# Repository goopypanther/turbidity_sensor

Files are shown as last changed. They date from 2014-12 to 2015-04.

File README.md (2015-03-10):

Water Turbidity Sensor Project
==============================

Hackerbot labs would like to place a number of water turbidity sensor packages in dive sites around Puget Sound to provide up-to-date visibility and water temperature information.

The sensor string will be suspended between a weight and small buoy which will contain a battery, solar panels and communication antenna. The installations will be close to shore and will probably use local wifi or a LTE cellular data connection.

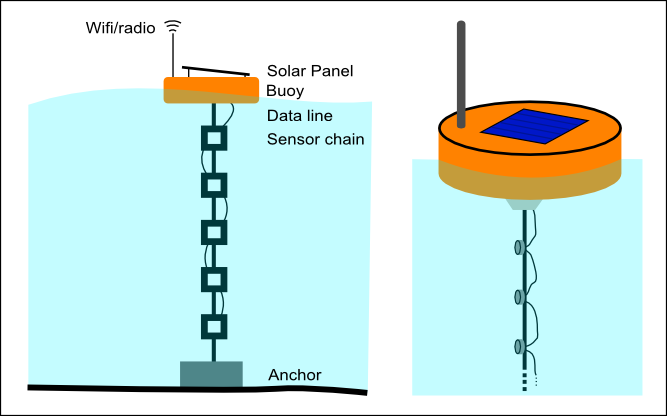
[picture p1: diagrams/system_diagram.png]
image of system diagram


Research
--------

[This folder](https://github.com/JeremyRuhland/turbidity_sensor/tree/master/research) contains information and design specs related to the sensor packages and their installation.

Prototypes
----------

[This folder](https://github.com/JeremyRuhland/turbidity_sensor/tree/master/prototypes) contains schematics and code used for prototype systems intented to guide the design of the sensors and their housings.

Designs
-------

[This folder](https://github.com/JeremyRuhland/turbidity_sensor/tree/master/designs) contains possible designs for the production sensor strings.

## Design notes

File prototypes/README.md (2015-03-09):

Prototypes
==========

Rev0
----

[This prototype](https://github.com/JeremyRuhland/turbidity_sensor/tree/master/prototypes/rev0) is the original design [JeremyRuhland](https://github.com/JeremyRuhland) came up with without doing any research or testing, so it probably won't work. This will probably never see the water but some design aspects may be useful for further equipment.

Rev1
----

[This prototype](https://github.com/JeremyRuhland/turbidity_sensor/tree/master/prototypes/rev1) is designed for testing differences between opacity measurements and rayleigh scattering. It is described further in its own readme file.

Rev2
----

[This prototype](https://github.com/JeremyRuhland/turbidity_sensor/tree/master/prototypes/rev2) is designed for testing the utility of UV light based biofouling mitigation. It is described further in its own readme file.

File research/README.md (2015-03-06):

Research
========

Research materials and notes go here.

Turbidity
---------

Particles both scatter and absorb light, scattered light may be a better indicator of clarity than absorbed light because of translucent particles.

Research suggests infrared light is ideal for its indifference to the color of particular organic particles. 940nm (IR) LEDs and photodiodes are readily available. 850nm (closer to NIR) are also an option.

Biofouling
----------

Research suggests ultraviolet light can reduce the amount of biological growth on sensor surfaces. UVC will kill everything from barnacles to biofilms ([1](https://www.ncbi.nlm.nih.gov/pubmed/20024789), [2](https://www.oceannews.com/feature-story/2014/03/04/february-uv-irradiation-a-new-kind-of-antifoulant)) but LEDs are very expensive (>$100 each). Cheap UVA LEDs may provide some protection ([1](http://onlinelibrary.wiley.com/doi/10.1111/j.1365-2672.2010.04850.x/full)) but other studies seem to indicate that some species respond favorably to it ([1](http://plankt.oxfordjournals.org/content/16/12/1645.short), [2](https://www.ncbi.nlm.nih.gov/pubmed/17039372)), though this might differ between soil/freshwater/marine environments.

Measurement & Conversion
------------------------

Some possible discussed architectures:

 * Direct measurement of photodiodes
 * Transimpedence amplifier -> ADC
 * Closed loop LED intensity/transimpedence -> ADC
  * Automatic gain control

Other ideas include:

 * Dark current subtraction on each measurement
 * Pulse/frequency coding LED flashes for noise immunity
 * Temperature compensation on photodiodes
 * Differential sensing at 2 different distances/difference amplifier
  * Corrects for ambient light and temp effects

ADC
---

Internal microcontroller ADC may be of lower quality than desired. External chip option is strong.

Jeremy: I'm tempted by the kinetis M series microcontrollers that have 24-bit delta/sigma ADCs.

Sensor Communications
---------------------

Need robust communication bus between sensors at different depths. RS485 is a good contender.

Shore Communications
--------------------

Possibilities:

 * WiFi link to nearby shore internet
  * Super simple, some dive sites have wifi available from nearby venues
 * LTE/GSM radiomodem
  * Works for remote sites
 * Zigbee/802.15.4/nrf24 based radio link to internet connected shore station
  * Unlikely to be better than radiomodem solution

Enclosures & Waterproofing
--------------------------

Ideas:

 * Inductive charge/data with fully encapsulated modules
 * Modules in individual watertight enclosures
 * Daisy-chained modules for simplicity
 * Enclosureless modules encapsulated in epoxy
  * Rubberized cable/pcb interface to prevent leakage around cables

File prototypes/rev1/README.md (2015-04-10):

This prototype is intended to test the behavior of IR LED/photodiode pairs at a variety of angles to narrow down the best method of obtaining measurements of water turbidity (direct opacity measurement/rayleigh scattering).

Each photodiode is connected to a transimpedance amplifier and broken out to a header for oscope/adc conversion. Everything should get wired up and then coated with epoxy so we can dunk it.

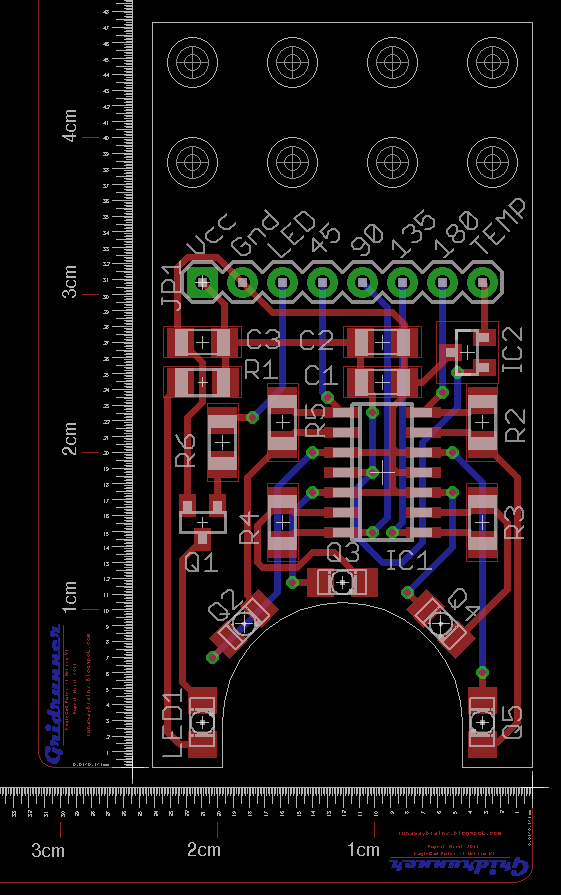
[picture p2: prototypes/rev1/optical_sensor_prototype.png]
image of pcb design


Schematic is easily [viewable in pdf form](https://github.com/JeremyRuhland/turbidity_sensor/raw/master/prototypes/rev1/optical_sensor_prototype.pdf)

Calcuations
-----------

Infrared LED current limit:

    3.3V
     |
     R --- 1.69V drop & 70mA = 24.25Ohm @ 118mW
     |
    LED -- 70mA @ 1.6V & 112mW
     |
    FET -- 29mOhm * 70mA = 0.00203V & 142uW
     |
    GND

Photodiode transimpedance amplifier feedback:

Photodiode should have a reverse light current on the order of several microamps, a 10kOhm feedback resistor will amplify this into the range of tens of millivolts.

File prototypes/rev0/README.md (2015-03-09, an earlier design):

This is an early version of an AVR based LED/photodiode measurement board with a daisy-chainable RS-485 communication bus.

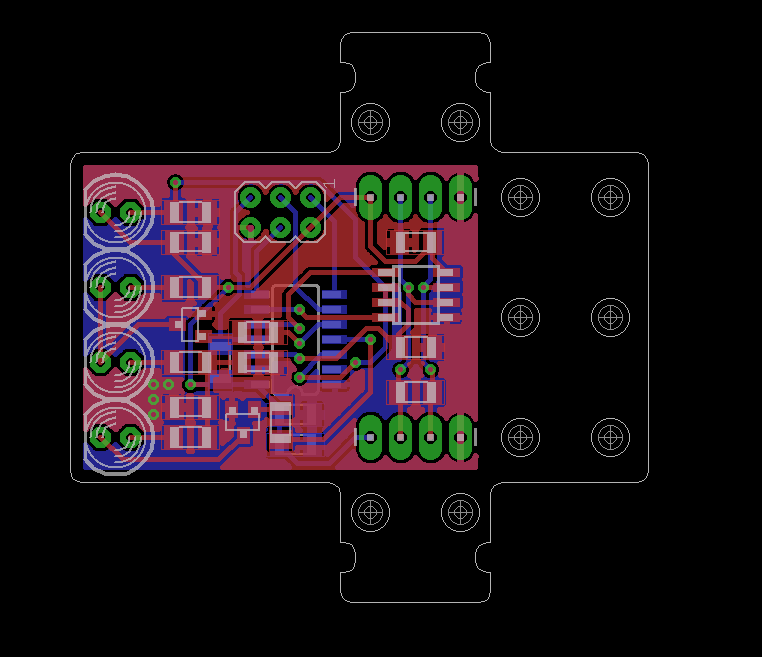
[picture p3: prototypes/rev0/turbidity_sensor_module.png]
image of pcb design


Schematic is easily [viewable in pdf form](https://github.com/JeremyRuhland/turbidity_sensor/raw/master/prototypes/rev0/turbidity_sensor_module.pdf)

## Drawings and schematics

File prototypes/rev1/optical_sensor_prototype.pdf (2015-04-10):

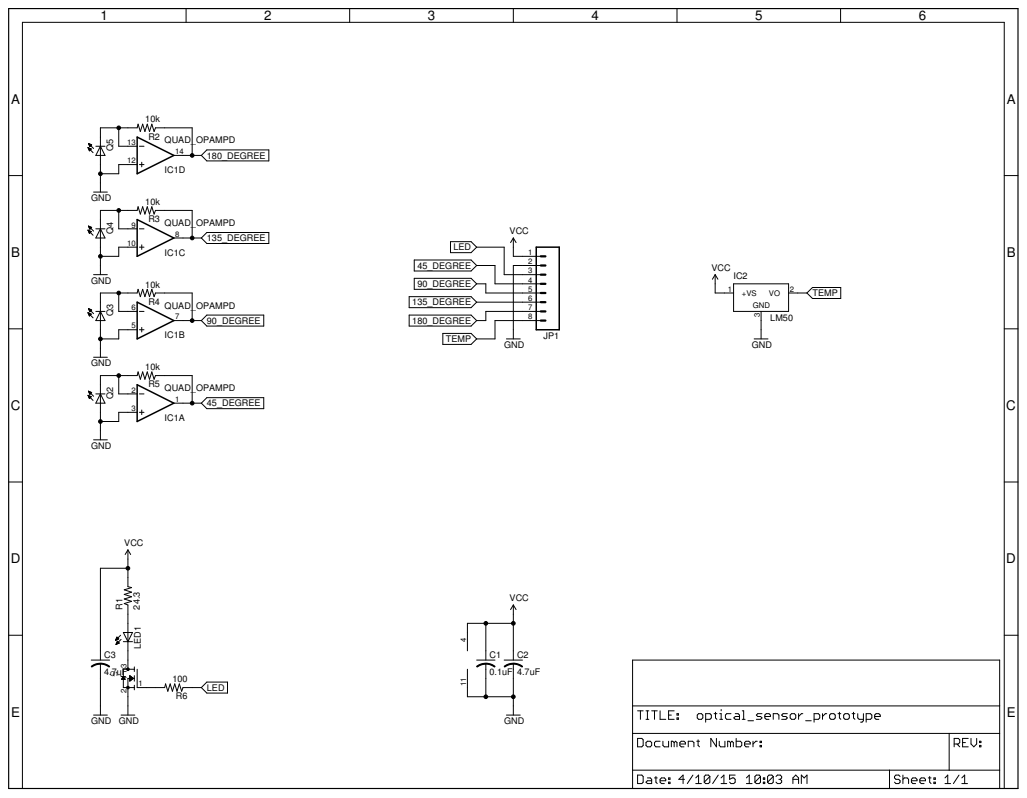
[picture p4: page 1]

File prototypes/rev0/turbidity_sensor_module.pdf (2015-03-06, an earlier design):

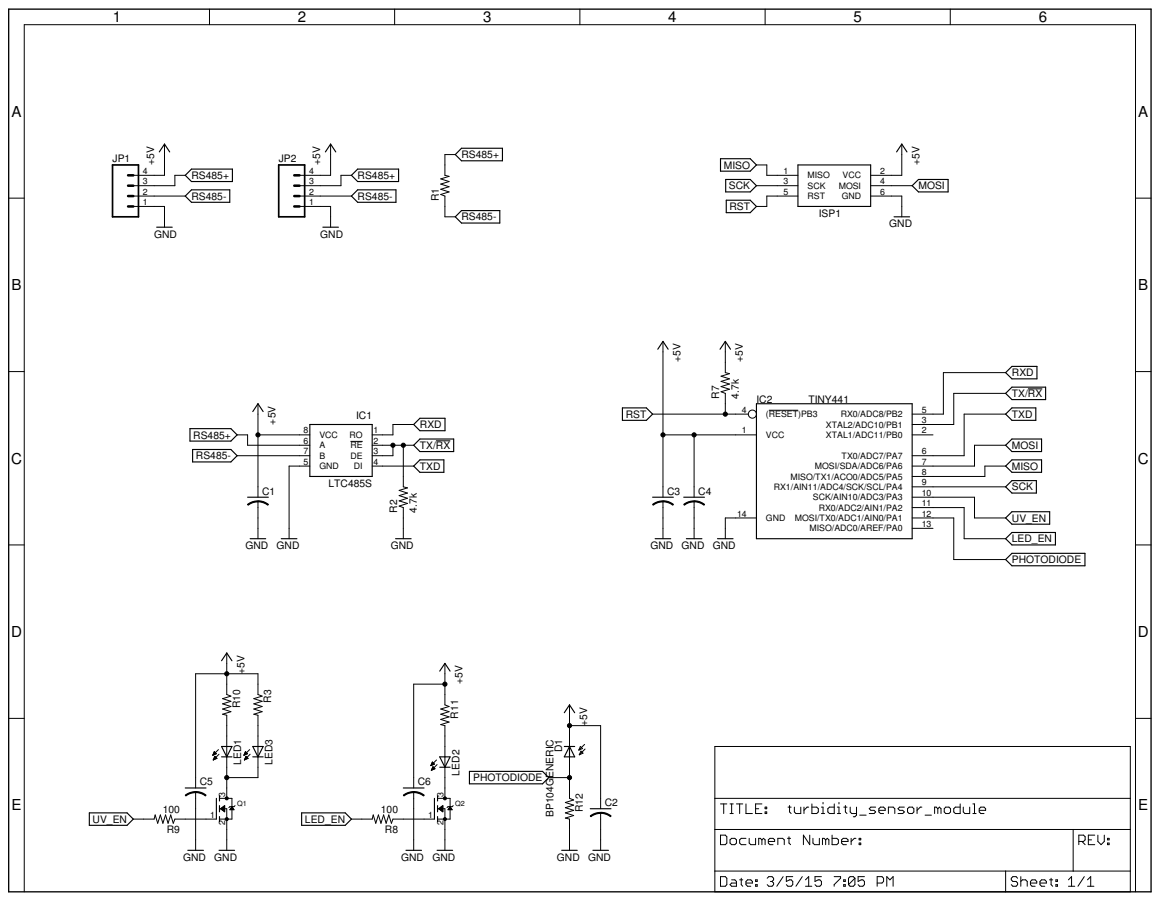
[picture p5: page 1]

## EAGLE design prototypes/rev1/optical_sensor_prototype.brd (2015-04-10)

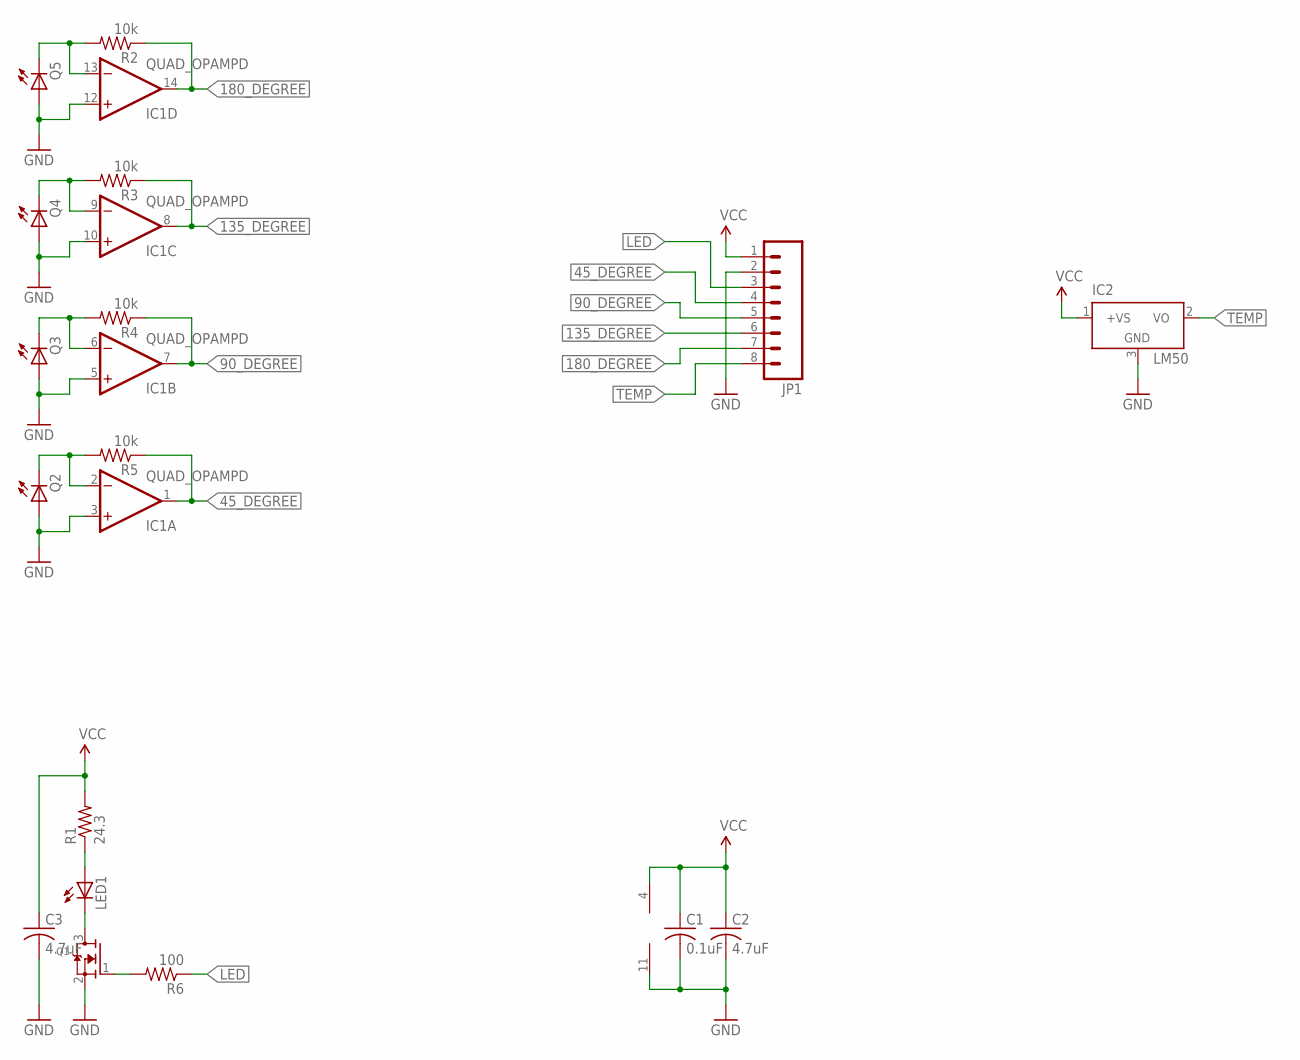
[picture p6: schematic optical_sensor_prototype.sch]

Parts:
C1: 0.1uF; C1206
C2, C3: 4.7uF; C1206
IC1: QUAD_OPAMPD; SO14
IC2: LM50; SOT23
JP1: M081X08; 1X08
LED1: LEDSMT1206; 1206
Q1: MOSFET-NREFLOW; SOT23
Q2, Q3, Q4, Q5: LEDSMT1206; 1206
R1: 24.3; R1206
R2, R3, R4, R5: 10k; R1206
R6: 100; R1206

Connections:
45_DEGREE: IC1.1 (OUT), JP1.4, R5.1
90_DEGREE: IC1.7 (OUT), JP1.5, R4.1
135_DEGREE: IC1.8 (OUT), JP1.6, R3.1
180_DEGREE: IC1.14 (OUT), JP1.7, R2.1
GND: C1.2, C2.2, C3.2, IC1.3 (+IN), IC1.5 (+IN), IC1.10 (+IN), IC1.11 (V-), IC1.12 (+IN), IC2.3 (GND), JP1.2, Q1.2 (S), Q2.A, Q3.A, Q4.A, Q5.A
LED: JP1.3, R6.1
unnamed: LED1.A, R1.1
unnamed: IC1.2 (-IN), Q2.C, R5.2
unnamed: LED1.C, Q1.3 (D)
unnamed: Q1.1 (G), R6.2
unnamed: IC1.6 (-IN), Q3.C, R4.2
unnamed: IC1.13 (-IN), Q5.C, R2.2
unnamed: IC1.9 (-IN), Q4.C, R3.2
TEMP: IC2.2 (VO), JP1.8
VCC: C1.1, C2.1, C3.1, IC1.4 (V+), IC2.1 (+VS), JP1.1, R1.2

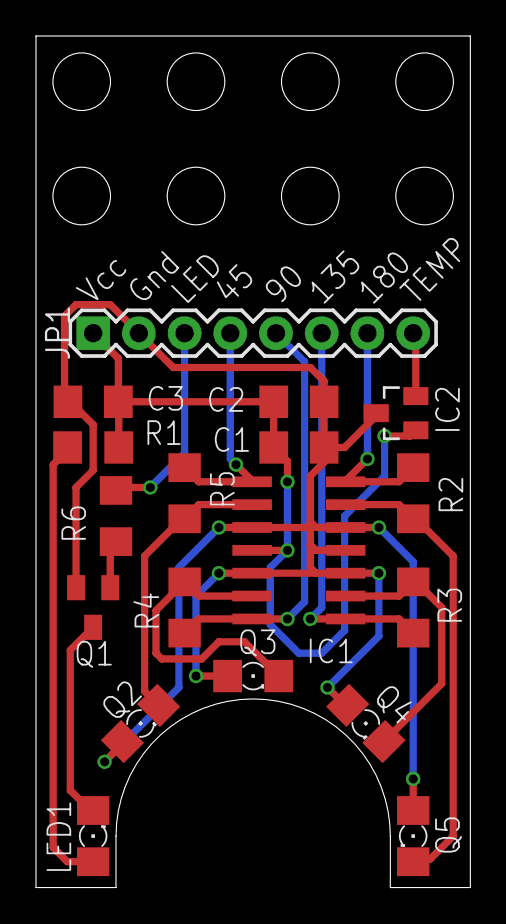
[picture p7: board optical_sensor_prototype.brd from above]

Board: 2 copper layers, 24.1 x 47.3 mm, 18 parts (0 on the bottom side), 15 nets.

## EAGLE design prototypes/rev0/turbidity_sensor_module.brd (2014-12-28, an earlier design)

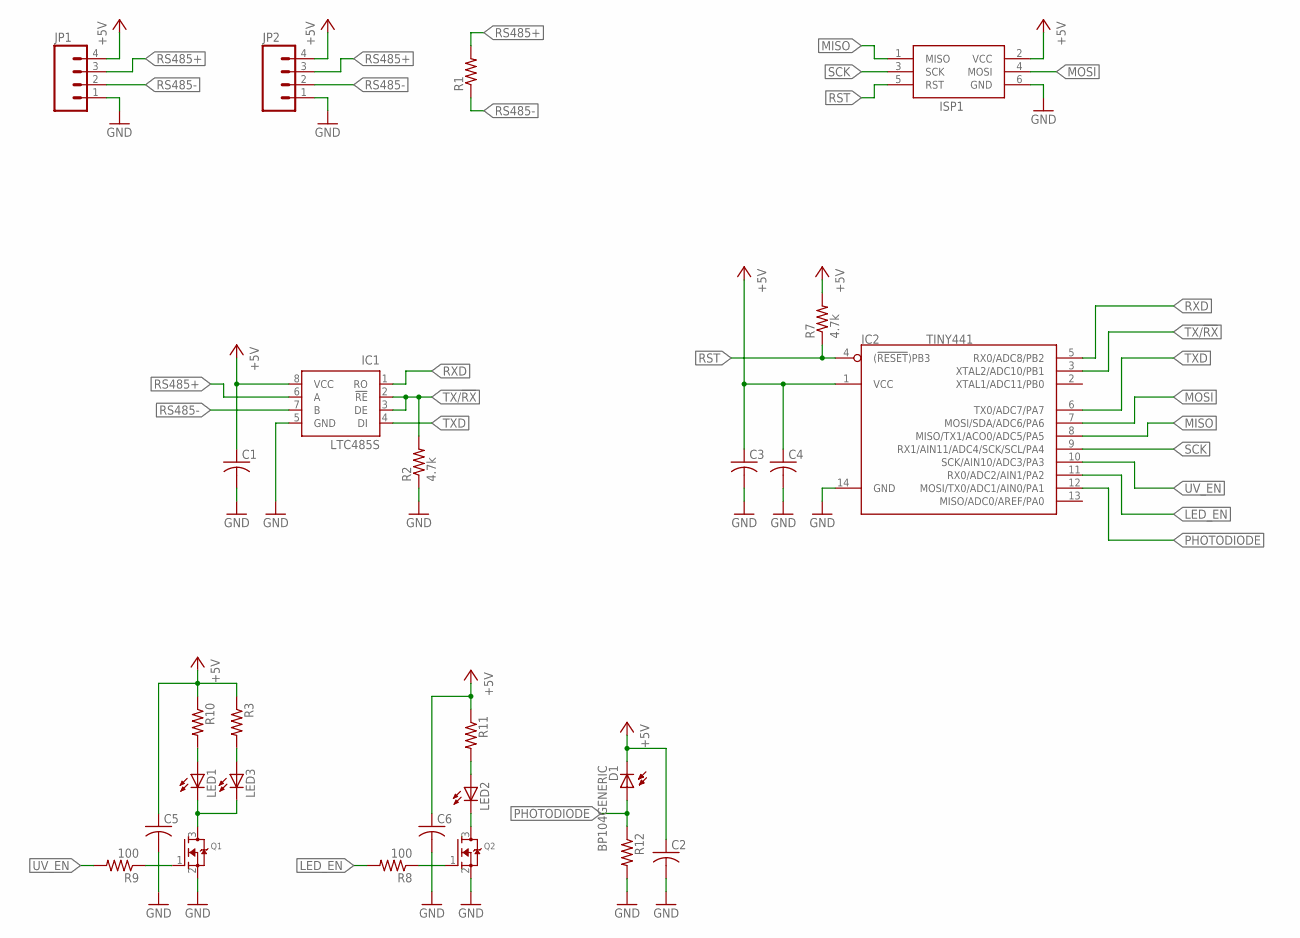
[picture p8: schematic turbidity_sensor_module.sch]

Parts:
C1, C2, C3, C4, C5, C6: C-USC1206; C1206
D1: BP104GENERIC; PHOTODIODE
IC1: LTC485S; SOIC8
IC2: TINY441; SOIC14
ISP1: AVRISP-6; AVRISP
JP1, JP2: M04LONGPADS; 1X04_LONGPADS
LED1, LED2, LED3: LED5MM
Q1, Q2: MOSFET-NREFLOW; SOT23
R1, R3, R10, R11, R12: R-US_R1206; R1206
R2, R7: 4.7k; R1206
R8, R9: 100; R1206

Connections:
+5V: C1.1, C2.1, C3.1, C4.1, C5.1, C6.1, D1.K (C), IC1.8 (VCC), IC2.1 (VCC), ISP1.2 (VCC), JP1.4, JP2.4, R3.1, R7.2, R10.1, R11.1
GND: C1.2, C2.2, C3.2, C4.2, C5.2, C6.2, IC1.5 (GND), IC2.14 (GND), ISP1.6 (GND), JP1.1, JP2.1, Q1.2 (S), Q2.2 (S), R2.1, R12.2
LED_EN: IC2.11 (RX0/ADC2/AIN1/PA2), R8.2
MISO: IC2.8 (MISO/TX1/ACO0/ADC5/PA5), ISP1.1 (MISO)
MOSI: IC2.7 (MOSI/SDA/ADC6/PA6), ISP1.4 (MOSI)
unnamed: Q2.1 (G), R8.1
unnamed: Q1.1 (G), R9.1
unnamed: LED1.A, R10.2
unnamed: LED2.A, R11.2
unnamed: LED1.K (C), LED3.K (C), Q1.3 (D)
unnamed: LED2.K (C), Q2.3 (D)
unnamed: LED3.A, R3.2
PHOTODIODE: D1.A, IC2.12 (MOSI/TX0/ADC1/AIN0/PA1), R12.1
RS485+: IC1.6 (A), JP1.3, JP2.3, R1.2
RS485-: IC1.7 (B), JP1.2, JP2.2, R1.1
RST: IC2.4 ((!RESET!)PB3), ISP1.5 (RST), R7.1
RXD: IC1.1 (RO), IC2.5 (RX0/ADC8/PB2)
SCK: IC2.9 (RX1/AIN11/ADC4/SCK/SCL/PA4), ISP1.3 (SCK)
TX/!RX: IC1.2 (!RE), IC1.3 (DE), IC2.3 (XTAL2/ADC10/PB1), R2.2
TXD: IC1.4 (DI), IC2.6 (TX0/ADC7/PA7)
UV_EN: IC2.10 (SCK/AIN10/ADC3/PA3), R9.2

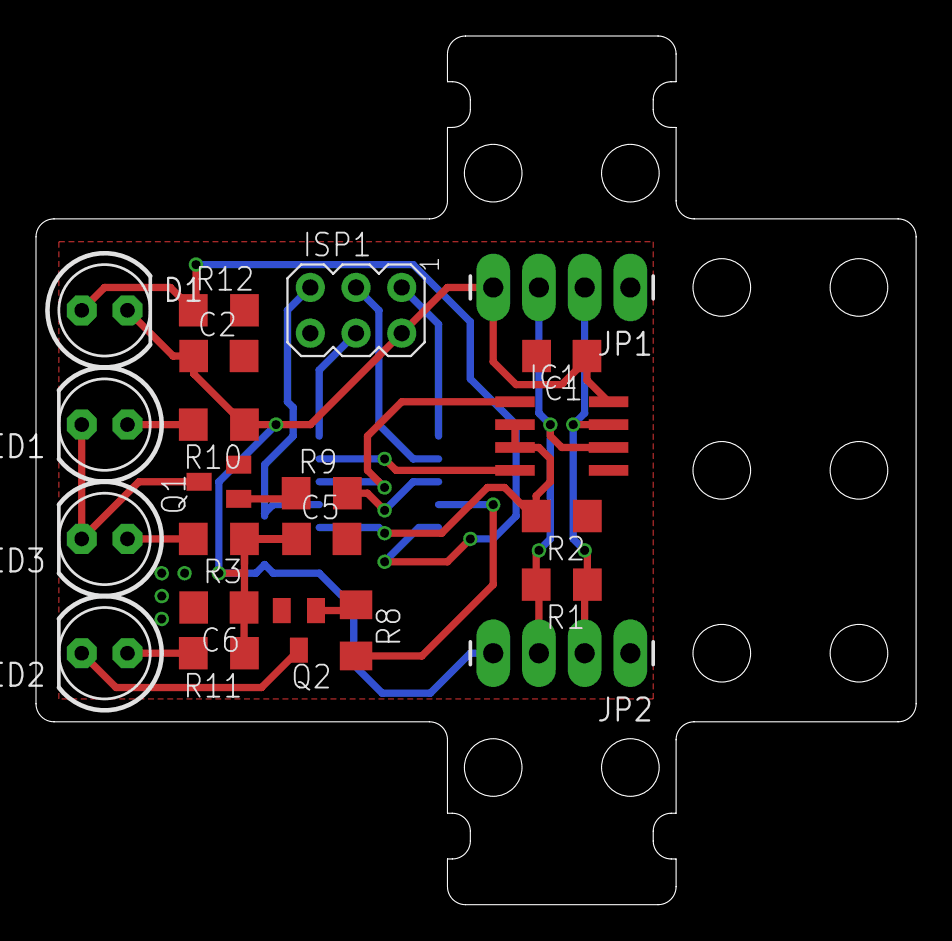
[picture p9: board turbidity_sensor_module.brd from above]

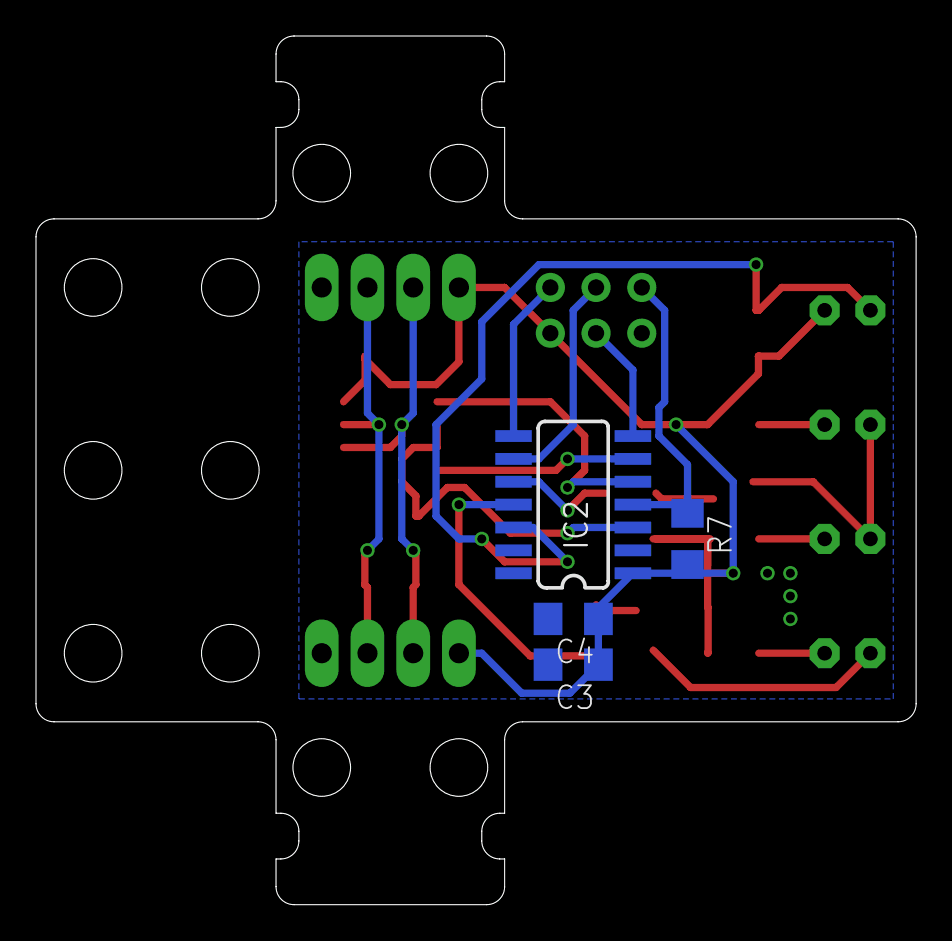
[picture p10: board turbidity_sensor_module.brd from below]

Board: 2 copper layers, 48.9 x 48.3 mm, 26 parts (4 on the bottom side), 21 nets.

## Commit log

2014-12-20 current progress on turbidity sensor module
    [turbidity_sensor_module.sch]
2014-12-28 finishing touches, layed out pcb
    [turbidity_sensor_module.brd, turbidity_sensor_module.sch]
2015-03-06 Put files into new folders
    [turbidity_sensor_module.brd, turbidity_sensor_module.sch]
2015-03-06 Started design of prototype optical sensor
    [optical_sensor_prototype.brd, optical_sensor_prototype.sch]
2015-03-06 some datasheets for the optical sensor prototype
2015-03-06 added prototype rev1 readme
2015-03-06 enclosure ideas
2015-03-09 prototype readme file, need to move rev0 here and create rev2
2015-03-09 moved rev0 to prototypes folder
    [turbidity_sensor_module.brd, turbidity_sensor_module.sch]
2015-04-10 added remaining component values
    [optical_sensor_prototype.brd, optical_sensor_prototype.sch]

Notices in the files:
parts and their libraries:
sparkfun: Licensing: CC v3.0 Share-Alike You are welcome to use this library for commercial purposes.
